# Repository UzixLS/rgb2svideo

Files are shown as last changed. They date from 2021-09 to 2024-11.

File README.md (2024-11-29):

## RGB2SVIDEO

This device converts 15KHz RGB + Sync analog video signal to S-Video or CVBS (composite) signal.
Both PAL and NTSC are supported (you should choose one at build).

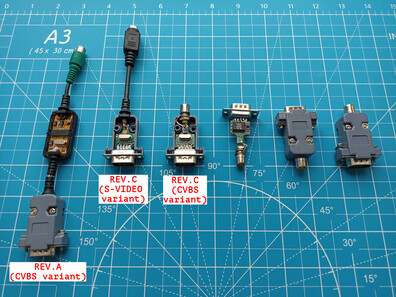
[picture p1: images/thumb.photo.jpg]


### Revision C PCB
This PCB is based on AD724 chip and designed to fit into DSUB shell.

[release/pcb.rev.C.pdf](release/pcb.rev.C.pdf?raw=true) - schematic and bill of materials  
[release/bom_interactive.rev.C.html](https://htmlpreview.github.io/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) - interactive BOM  
[release/gerber.rev.C.zip](release/gerber.rev.C.zip) - fabrication files  

### Revision A PCB
This PCB is based on BH7236AF/KA2198BD/CXA1645/CXA2075 chips and designed to fit into AK-S-71 shell.

[release/pcb.rev.A2.pdf](release/pcb.rev.A2.pdf?raw=true) - schematic and bill of materials  
[release/bom_interactive.rev.A2.html](https://htmlpreview.github.io/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) - interactive BOM  
[release/gerber.rev.A2.zip](release/gerber.rev.A2.zip) - fabrication files

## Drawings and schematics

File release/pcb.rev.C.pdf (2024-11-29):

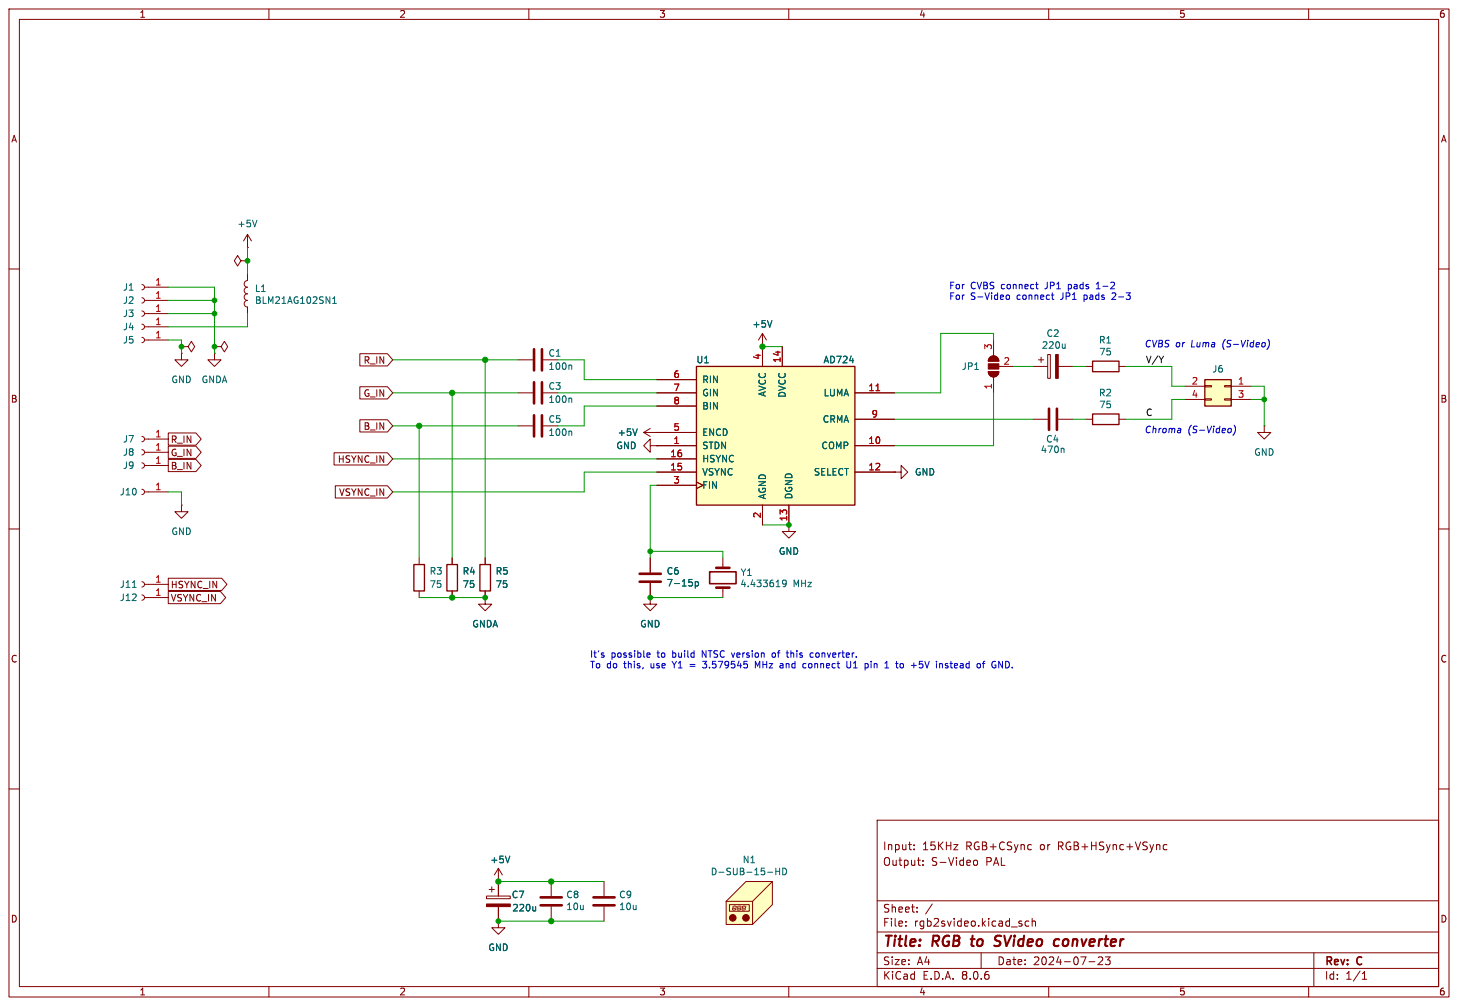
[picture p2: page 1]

4 ENCD 5 RIN 6 GIN 7 BIN 8 CRMA 9 U1 AD724 R3

4 ENCD 5 RIN 6 GIN 7 BIN 8 CRMA 9 GND

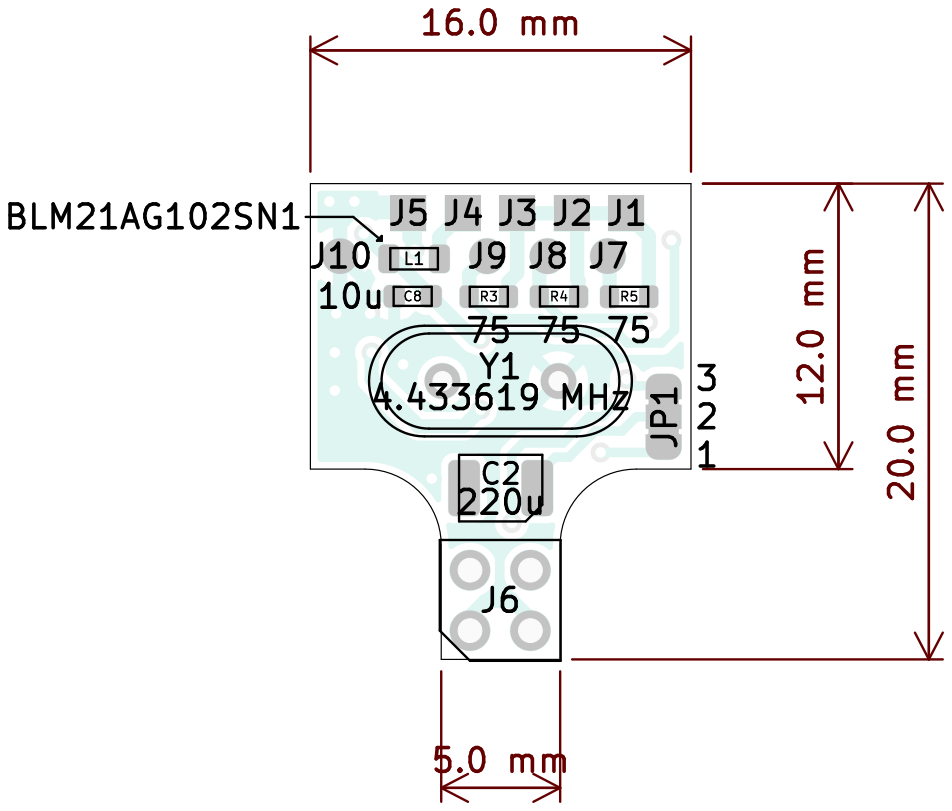
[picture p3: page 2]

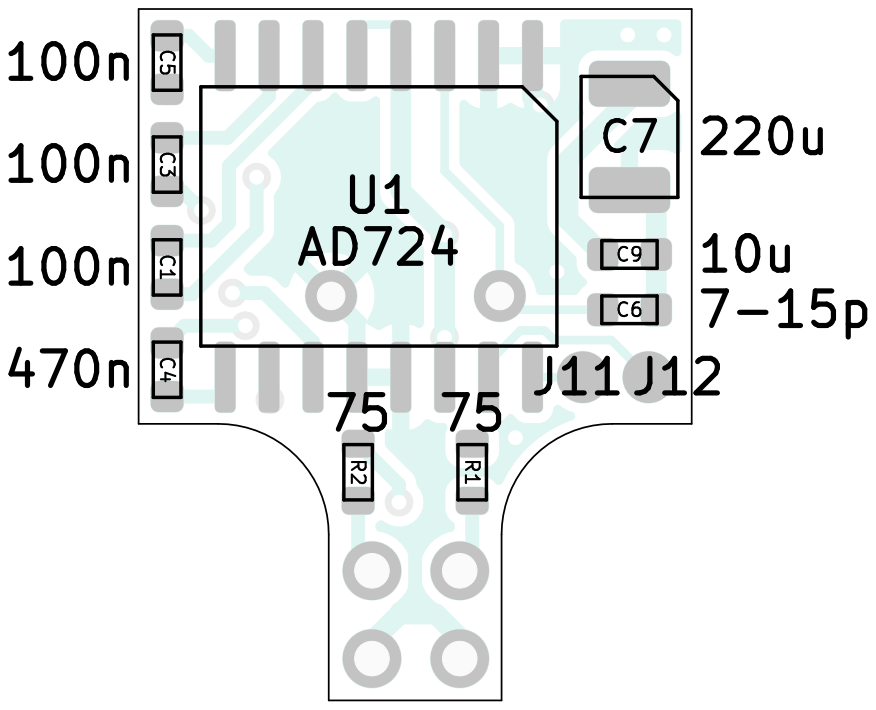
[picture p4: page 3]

# Bill Of Materials

References | | | Value | Footprint | Qty
C1 C3 C5 | 100n | Capacitor_SMD:C_0603_1608Metric | 3
C2 C7 | 220u | Capacitor_Tantalum_SMD:CP_EIA-3528-12_ Kemet-T | 2
C4 | 470n | Capacitor_SMD:C_0603_1608Metric | 1
C6 | 7-15p | Capacitor_SMD:C_0603_1608Metric | 1
C8 C9 | 10u | Capacitor_SMD:C_0603_1608Metric | 2
J6 | Conn_02x02_Odd_Even | Connector_PinHeader_2.54mm:PinHeader_2 x02_P2.54mm_Vertical | 1
L1 | BLM21AG102SN1 | Inductor_SMD:L_0805_2012Metric | 1
N1 | D-SUB-15-HD | | 1
R1 R2 R3 R4 R5 | 75 | Resistor_SMD:R_0603_1608Metric | 5
U1 | AD724 | Package_SO:SOIC-16W_7.5x10.3mm_P1.27 mm | 1
Y1 | 4.433619 MHz | Crystal:Crystal_HC49-4H_Vertical | 1

# rgb2svideo rev.C BOM page 1/1

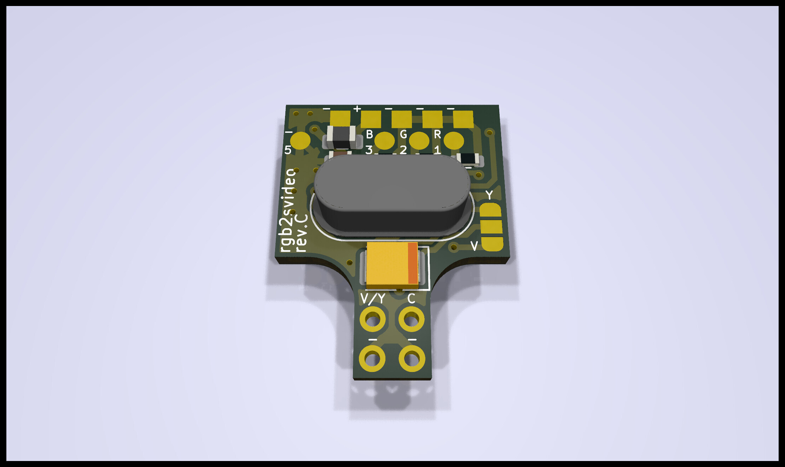
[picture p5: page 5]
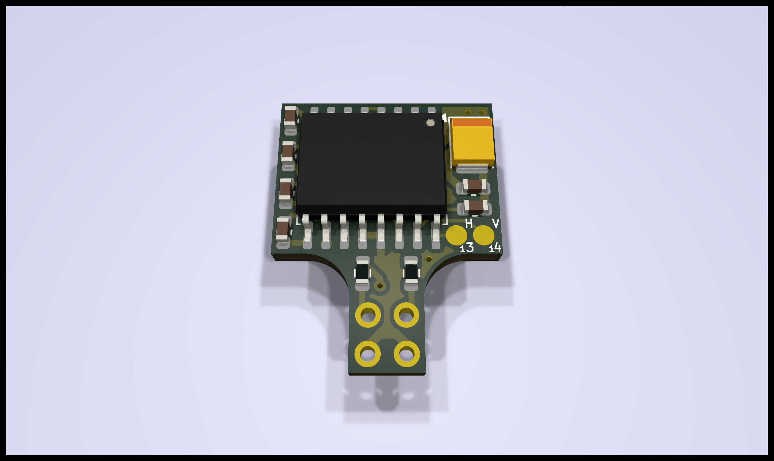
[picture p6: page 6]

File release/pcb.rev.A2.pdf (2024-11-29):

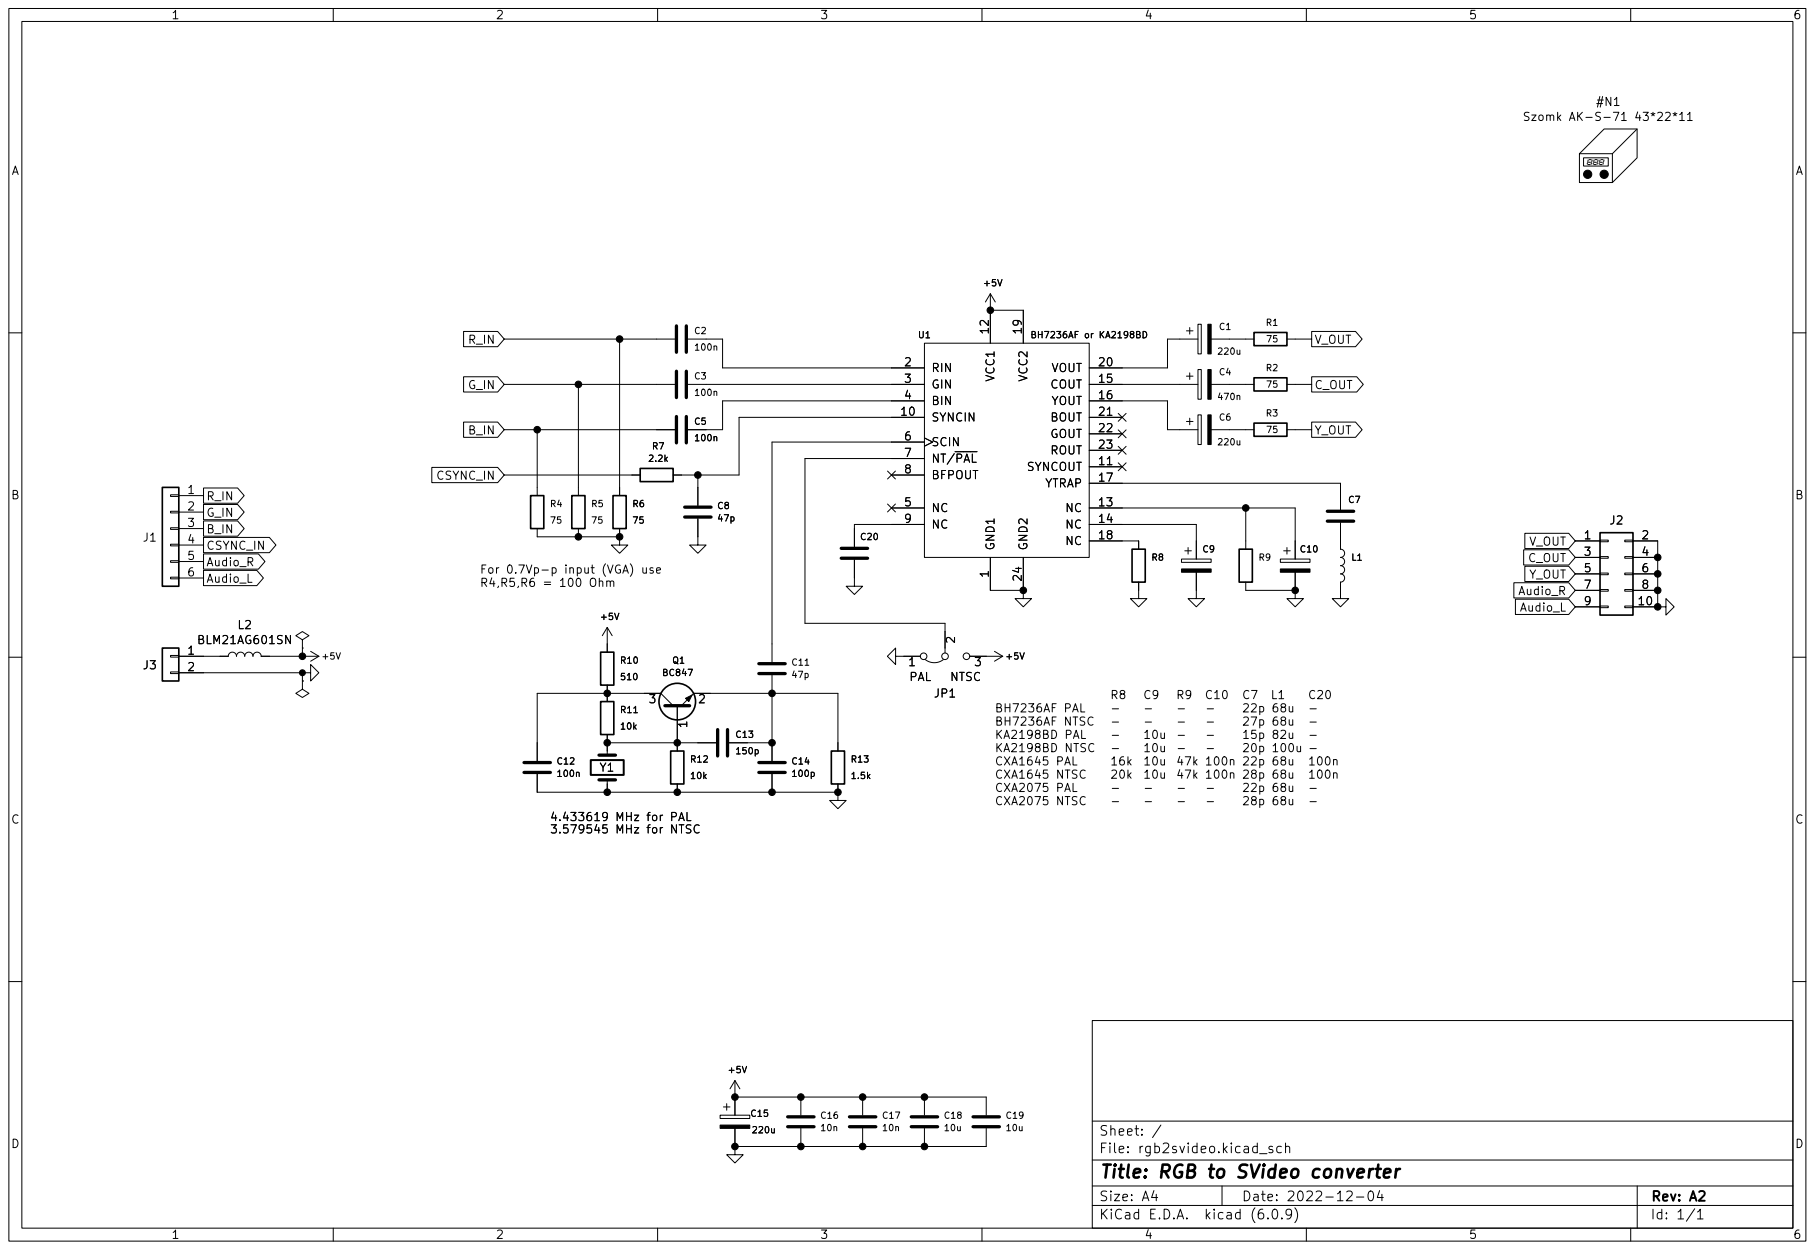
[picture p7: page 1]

For 0.7Vp-p input (VGA) use
R4,R5,R6 = 100 Ohm

Sheet: /
File: rgb2svideo.kicad_sch
Title: RGB to SVideo converter

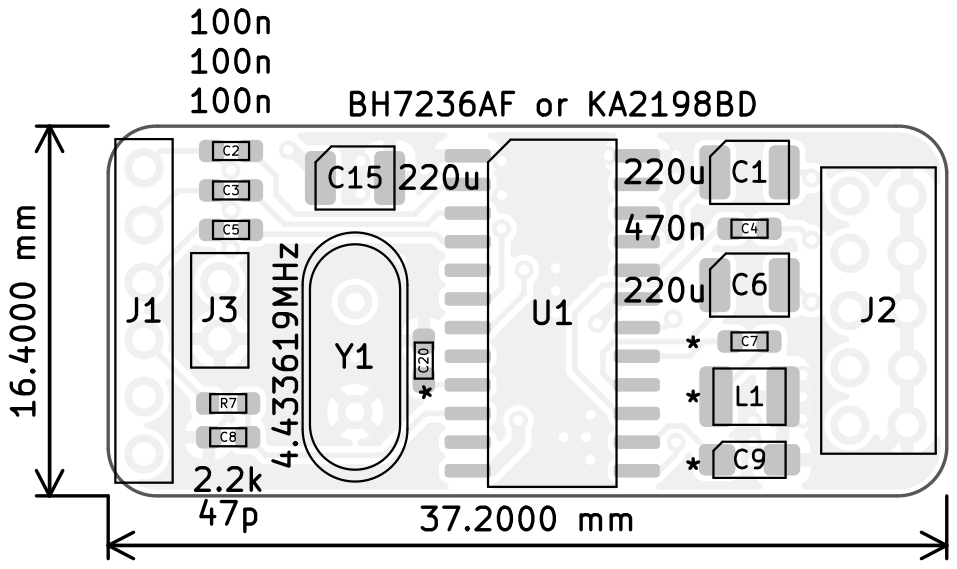
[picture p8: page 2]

Sheet: Assembly
File: rgb2svideo.kicad_pcb
Title: RGB to SVideo converter

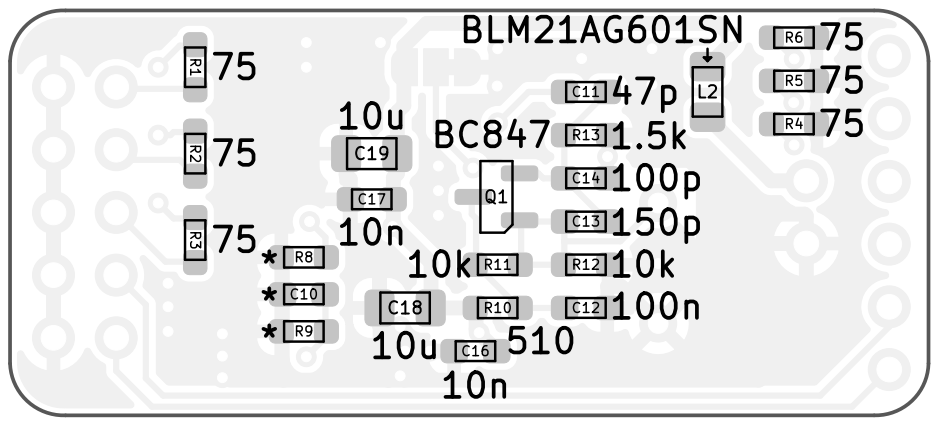
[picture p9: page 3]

Sheet: Assembly
File: rgb2svideo.kicad_pcb
Title: RGB to SVideo converter

Designator | Package | Value | Quantity
C1, C6, C15 | CP_EIA-3528-12_Kemet-T | 220u | 3
C2, C3, C5, C12 | C_0603_1608Metric_Pad1.08x0.95mm_HandSolder | 100n | 4
C4 | C_0603_1608Metric_Pad1.08x0.95mm_HandSolder | 470n | 1
C7, C10, C20 | C_0603_1608Metric_Pad1.08x0.95mm_HandSolder | * | 3
C8, C11 | C_0603_1608Metric_Pad1.08x0.95mm_HandSolder | 47p | 2
C9 | CP_EIA-3216-18_Kemet-A_Pad1.58x1.35mm_HandSolder | * | 1
C13 | C_0603_1608Metric_Pad1.08x0.95mm_HandSolder | 150p | 1
C14 | C_0603_1608Metric_Pad1.08x0.95mm_HandSolder | 100p | 1
C16, C17 | C_0603_1608Metric_Pad1.08x0.95mm_HandSolder | 10n | 2
C18, C19 | C_0805_2012Metric_Pad1.18x1.45mm_HandSolder | 10u | 2
L1 | L_1210_3225Metric_Pad1.42x2.65mm_HandSolder | * | 1
L2 | L_0805_2012Metric_Pad1.15x1.40mm_HandSolder | BLM21AG601SN | 1
Q1 | SOT-23 | BC847 | 1
R1, R2, R3, R4, R5, R6 | R_0603_1608Metric_Pad0.98x0.95mm_HandSolder | 75 | 6
R7 | R_0603_1608Metric_Pad0.98x0.95mm_HandSolder | 2.2k | 1
R8, R9 | R_0603_1608Metric_Pad0.98x0.95mm_HandSolder | * | 2
R10 | R_0603_1608Metric_Pad0.98x0.95mm_HandSolder | 510 | 1
R11, R12 | R_0603_1608Metric_Pad0.98x0.95mm_HandSolder | 10k | 2
R13 | R_0603_1608Metric_Pad0.98x0.95mm_HandSolder | 1.5k | 1
U1 | SOP-24_5.0x15.4mm_P1.27mm | BH7236AF or KA2198BD | 1
Y1 | Crystal_HC49-4H_Vertical | 4.433619MHz | 1

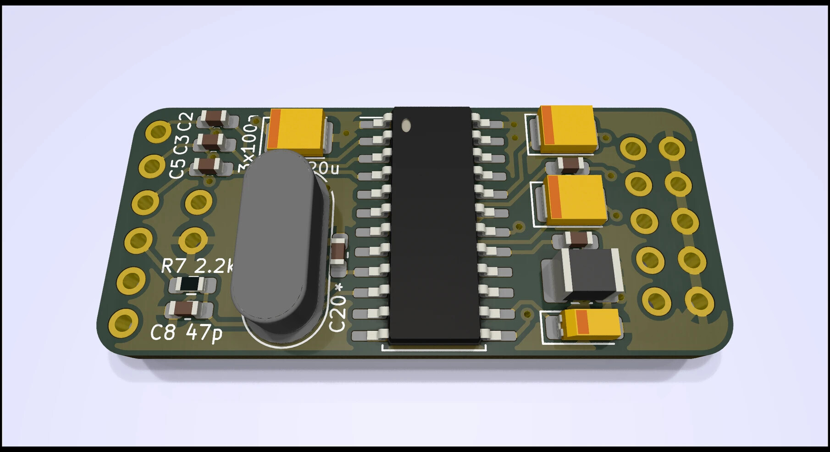
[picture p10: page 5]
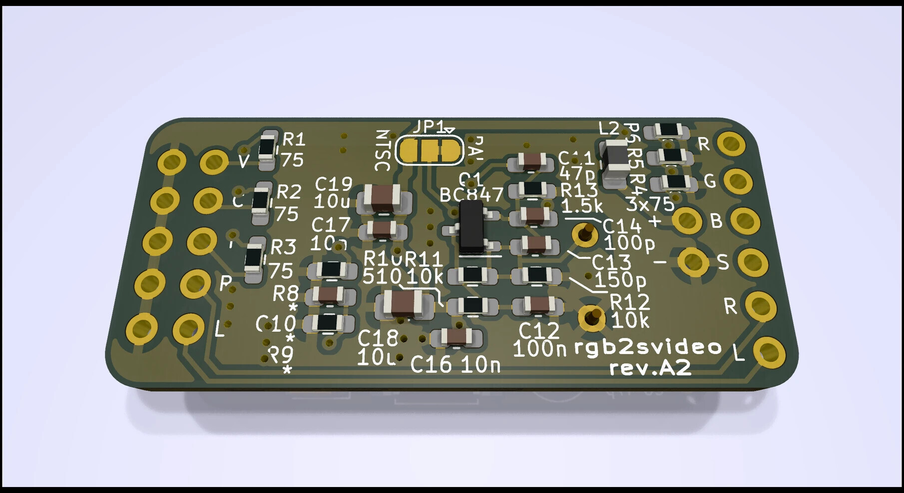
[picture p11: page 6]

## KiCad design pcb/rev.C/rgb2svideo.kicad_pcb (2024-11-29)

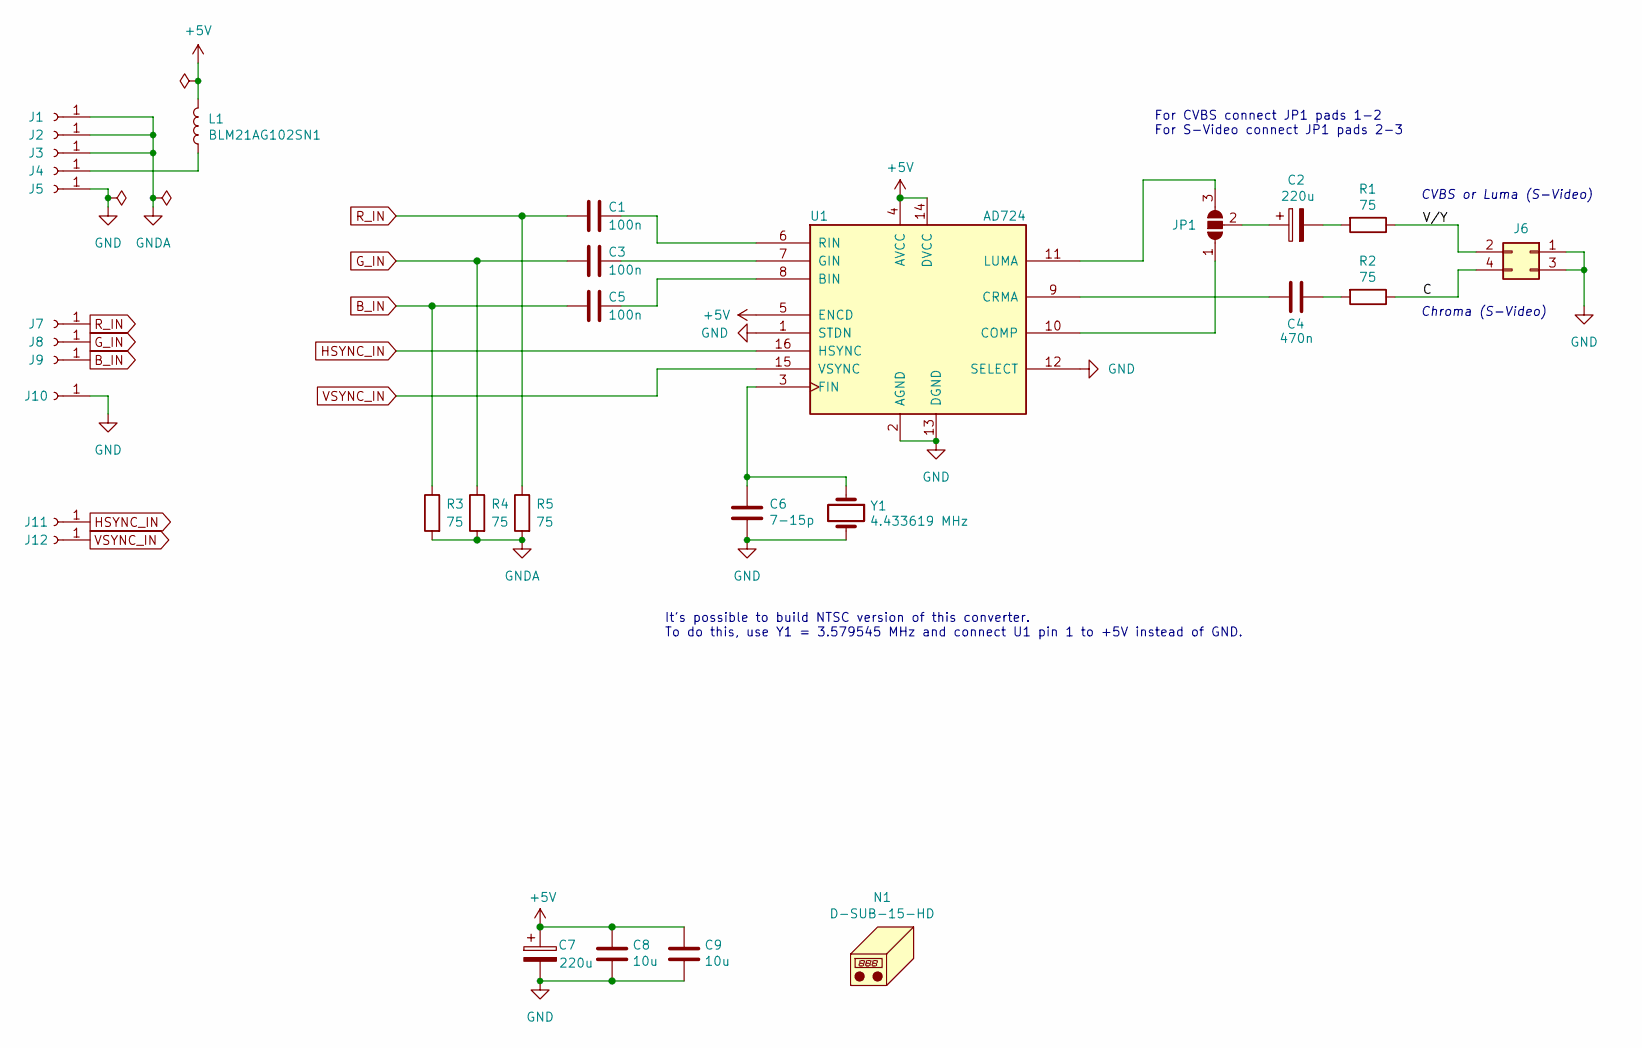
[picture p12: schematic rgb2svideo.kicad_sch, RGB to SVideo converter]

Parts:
C1, C3, C5: 100n; C_0603_1608Metric
C2, C7: 220u; CP_EIA-3528-12_Kemet-T
C4: 470n; C_0603_1608Metric
C6: 7-15p; C_0603_1608Metric
C8, C9: 10u; C_0603_1608Metric
J1, J2, J3, J4, J5: Conn_01x01_Socket; TestPoint_Pad_1.5x1.5mm
J6: Conn_02x02_Odd_Even; PinHeader_2x02_P2.54mm_Vertical
J7, J8, J9, J10, J11, J12: Conn_01x01_Socket; TestPoint_Pad_D1.5mm
JP1: SolderJumper_3_Bridged12; SolderJumper-3_P1.3mm_Open_RoundedPad1.0x1.5mm
L1: BLM21AG102SN1; L_0805_2012Metric
N1: D-SUB-15-HD
R1, R2, R3, R4, R5: 75; R_0603_1608Metric
U1: AD724; SOIC-16W_7.5x10.3mm_P1.27mm
Y1: 4.433619 MHz; Crystal_HC49-4H_Vertical

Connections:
+5V: C7.1, C8.1, C9.1, L1.2, U1.4 (AVCC), U1.5 (ENCD), U1.14 (DVCC)
/C: J6.4, R2.1
/V/Y: J6.2, R1.1
B_IN: C5.2, J9.1, R3.1
GND: C6.2, C7.2, C8.2, C9.2, J5.1, J6.1, J6.3, J10.1, U1.1 (STDN), U1.2 (AGND), U1.12 (SELECT), U1.13 (DGND), Y1.2
GNDA: J1.1, J2.1, J3.1, R3.2, R4.2, R5.2
G_IN: C3.2, J8.1, R4.1
HSYNC_IN: J11.1, U1.16 (HSYNC)
unnamed: C2.2, R1.2
unnamed: C4.2, R2.2
unnamed: J4.1, L1.1
unnamed: JP1.1 (A), U1.10 (COMP)
unnamed: JP1.3 (B), U1.11 (LUMA)
unnamed: C2.1, JP1.2 (C)
unnamed: C5.1, U1.8 (BIN)
unnamed: C4.1, U1.9 (CRMA)
unnamed: C6.1, U1.3 (FIN), Y1.1
unnamed: C3.1, U1.7 (GIN)
unnamed: C1.1, U1.6 (RIN)
R_IN: C1.2, J7.1, R5.1
VSYNC_IN: J12.1, U1.15 (VSYNC)

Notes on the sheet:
It's possible to build NTSC version of this converter. To do this, use Y1 = 3.579545 MHz and connect U1 pin 1 to +5V instead of GND.
For CVBS connect JP1 pads 1-2 For S-Video connect JP1 pads 2-3
CVBS or Luma (S-Video)
Chroma (S-Video)

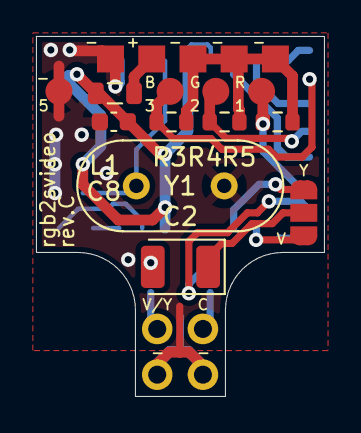
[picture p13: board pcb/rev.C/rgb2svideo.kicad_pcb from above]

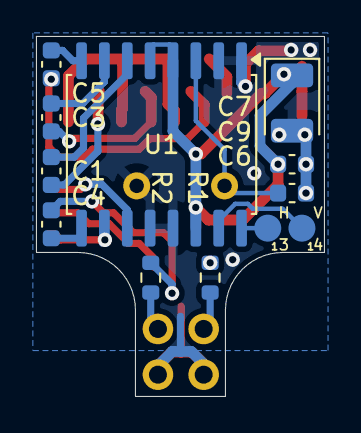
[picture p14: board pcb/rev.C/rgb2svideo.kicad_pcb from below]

Board: 2 copper layers, 16.0 x 20.0 mm, 30 parts (12 on the bottom side), 21 nets.

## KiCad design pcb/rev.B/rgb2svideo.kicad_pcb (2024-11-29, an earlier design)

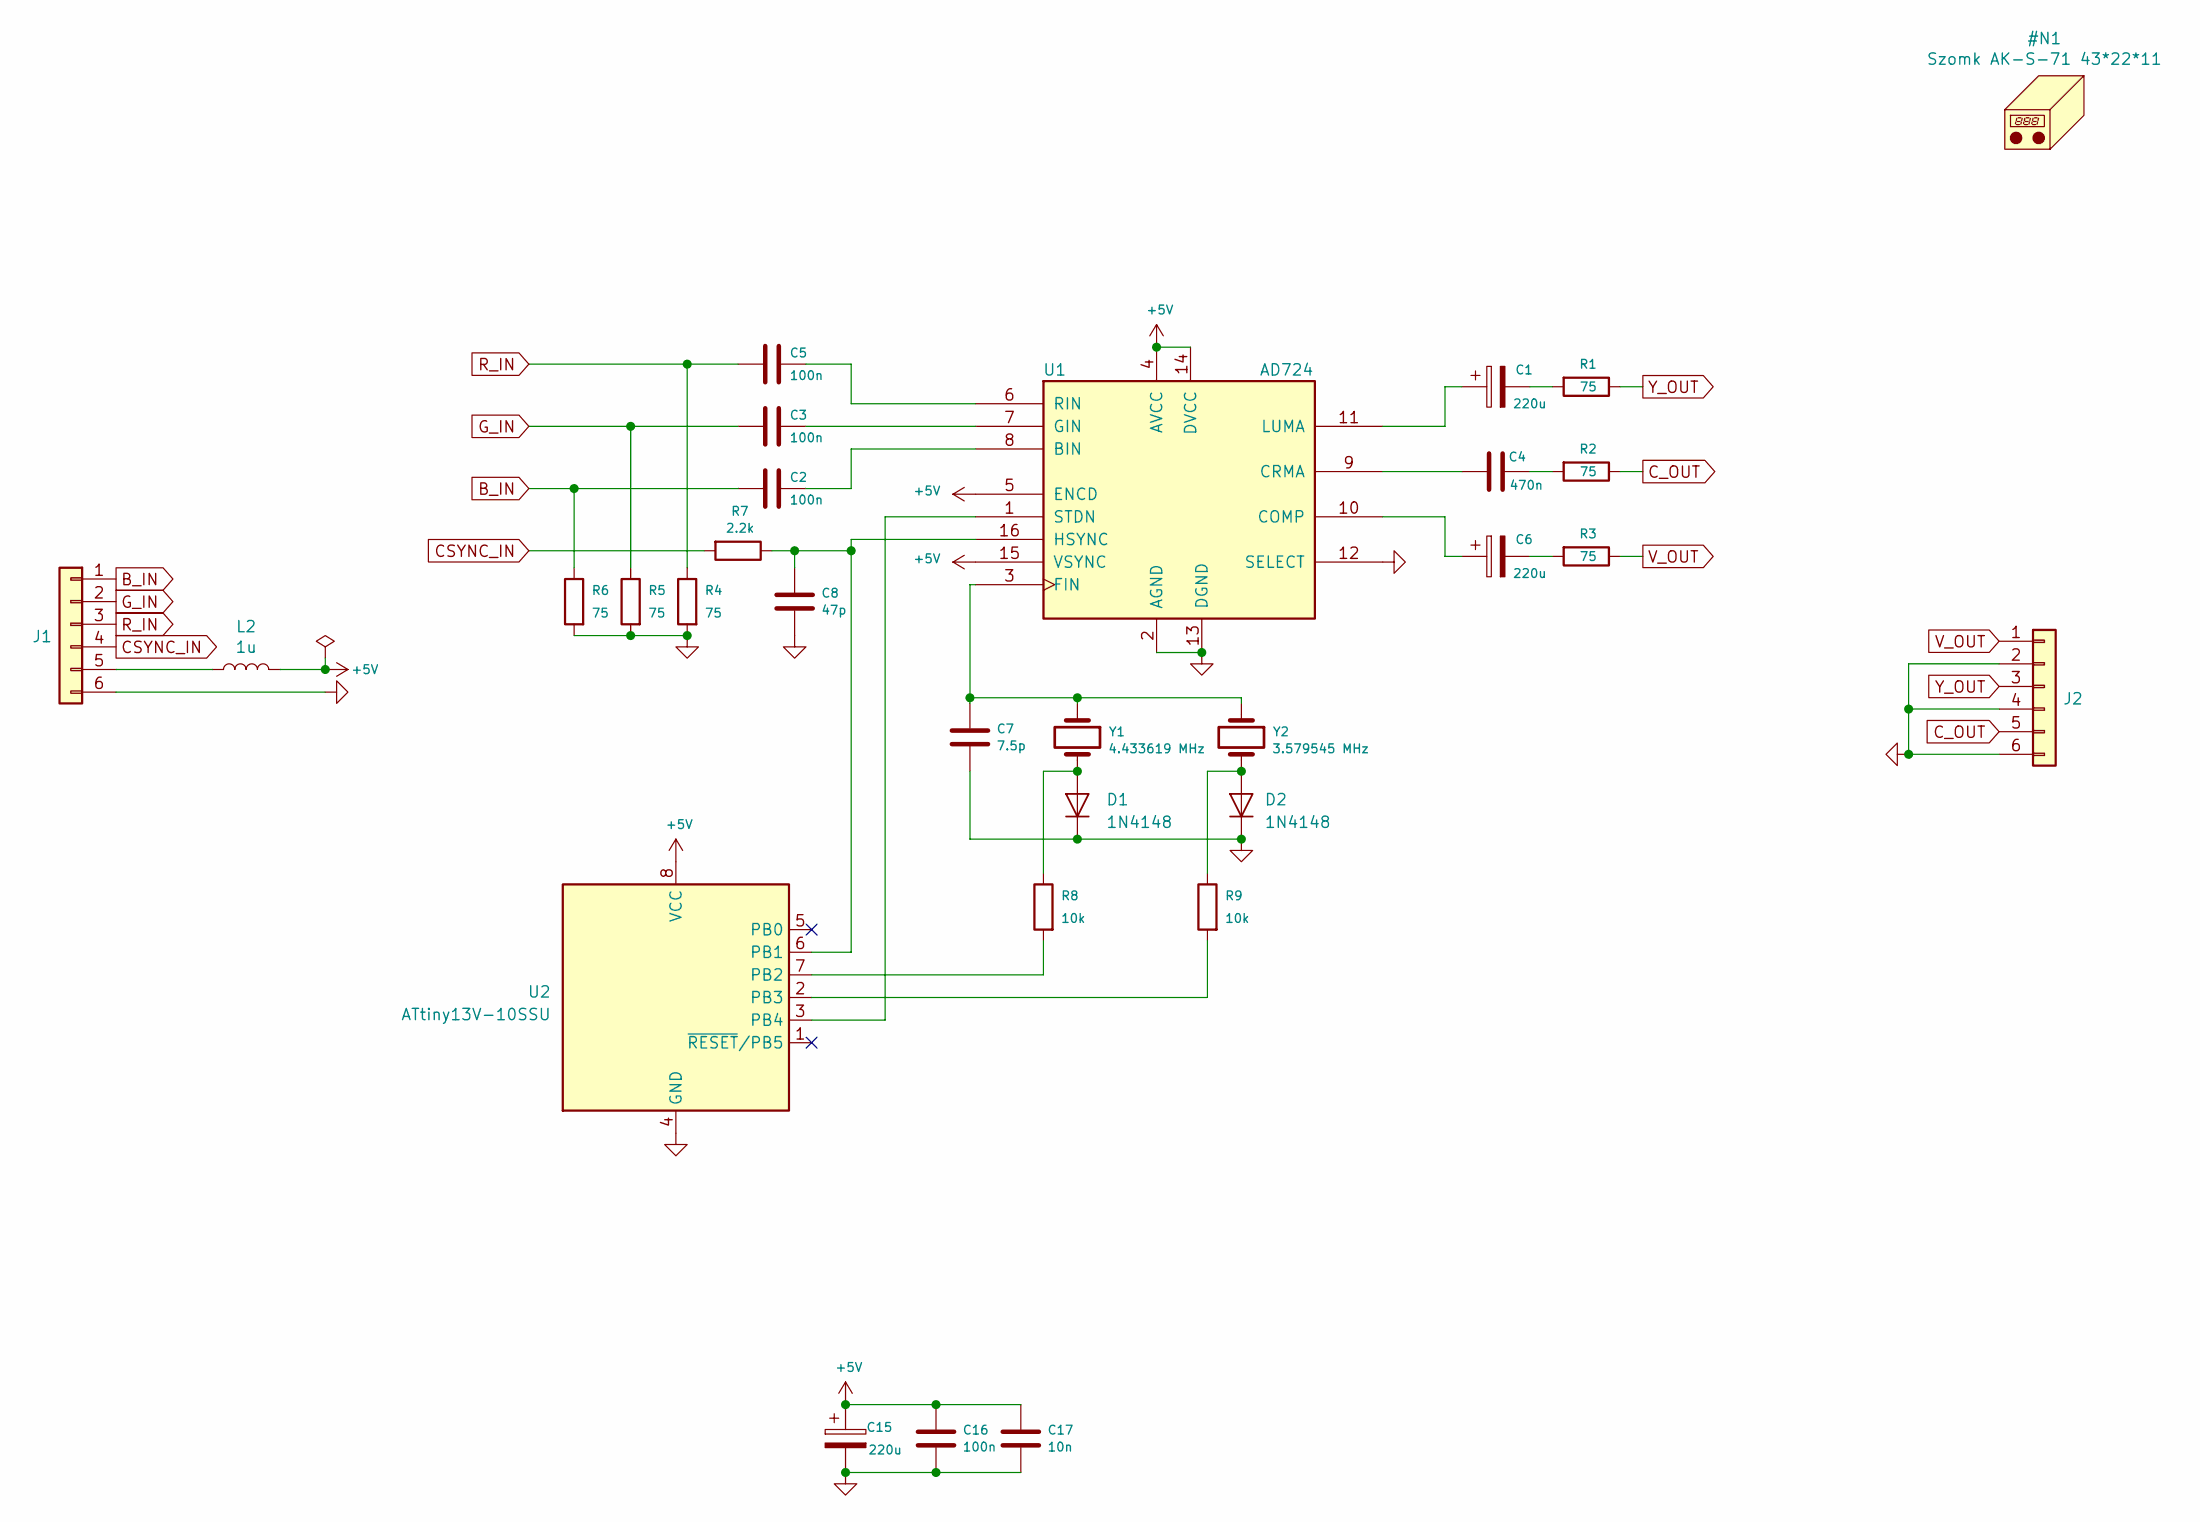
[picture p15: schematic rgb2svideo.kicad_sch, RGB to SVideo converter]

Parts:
C1, C6, C15: 220u; CP_EIA-3528-12_Kemet-T
C2, C3, C5: 100n; C_0603_1608Metric_Pad1.08x0.95mm_HandSolder
C4: 470n; C_0805_2012Metric_Pad1.18x1.45mm_HandSolder
C7: 7.5p; C_0603_1608Metric_Pad1.08x0.95mm_HandSolder
C8: 47p; C_0603_1608Metric_Pad1.08x0.95mm_HandSolder
C16: 100n; C_0603_1608Metric_Pad1.05x0.95mm_HandSolder
C17: 10n; C_0603_1608Metric_Pad1.05x0.95mm_HandSolder
D1, D2: 1N4148; D_0805_2012Metric_Pad1.15x1.40mm_HandSolder
J1, J2: Conn_01x06_Odd_Even; PinHeader_1x06_P2.54mm_Vertical
L2: 1u; L_0805_2012Metric_Pad1.15x1.40mm_HandSolder
R1, R2, R3, R4, R5, R6: 75; R_0603_1608Metric_Pad0.98x0.95mm_HandSolder
R7: 2.2k; R_0603_1608Metric_Pad0.98x0.95mm_HandSolder
R8, R9: 10k; R_0603_1608Metric_Pad0.98x0.95mm_HandSolder
U1: AD724; SOIC-16W_7.5x10.3mm_P1.27mm
U2: ATtiny13V-10SSU; SOIC-8_3.9x4.9mm_P1.27mm
Y1: 4.433619 MHz; Crystal_SMD_HC49-SD
Y2: 3.579545 MHz; Crystal_SMD_HC49-SD

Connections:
+5V: C15.1, C16.1, C17.1, L2.2, U1.4 (AVCC), U1.5 (ENCD), U1.14 (DVCC), U1.15 (VSYNC), U2.8 (VCC)
B_IN: C2.2, J1.1, R6.1
CSYNC_IN: J1.4, R7.2
C_OUT: J2.5, R2.1
GND: C7.2, C8.2, C15.2, C16.2, C17.2, D1.1 (K), D2.1 (K), J1.6, J2.2, J2.4, J2.6, R4.2, R5.2, R6.2, U1.2 (AGND), U1.12 (SELECT), U1.13 (DGND), U2.4 (GND)
G_IN: C3.2, J1.2, R5.1
unnamed: C1.1, U1.11 (LUMA)
unnamed: C1.2, R1.2
unnamed: C2.1, U1.8 (BIN)
unnamed: C3.1, U1.7 (GIN)
unnamed: C5.1, U1.6 (RIN)
unnamed: C6.1, U1.10 (COMP)
unnamed: C6.2, R3.2
unnamed: C8.1, R7.1, U1.16 (HSYNC), U2.6 (PB1)
unnamed: J1.5, L2.1
unnamed: C4.2, R2.2
unnamed: R8.2, U2.7 (PB2)
unnamed: R9.2, U2.2 (PB3)
unnamed: U1.1 (STDN), U2.3 (PB4)
unnamed: C7.1, U1.3 (FIN), Y1.1, Y2.1
unnamed: C4.1, U1.9 (CRMA)
unnamed: D1.2 (A), R8.1, Y1.2
unnamed: D2.2 (A), R9.1, Y2.2
R_IN: C5.2, J1.3, R4.1
V_OUT: J2.1, R3.1
Y_OUT: J2.3, R1.1

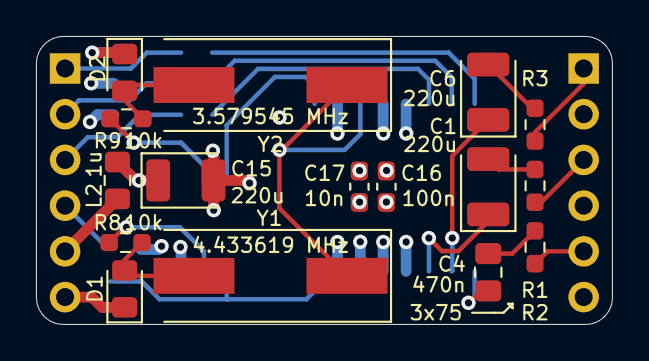
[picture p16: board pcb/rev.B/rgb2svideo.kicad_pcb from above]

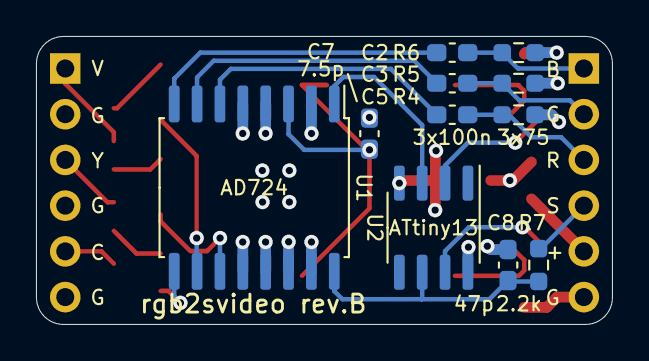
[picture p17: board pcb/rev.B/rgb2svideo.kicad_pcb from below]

Board: 4 copper layers, 32.0 x 16.0 mm, 29 parts (11 on the bottom side), 26 nets.

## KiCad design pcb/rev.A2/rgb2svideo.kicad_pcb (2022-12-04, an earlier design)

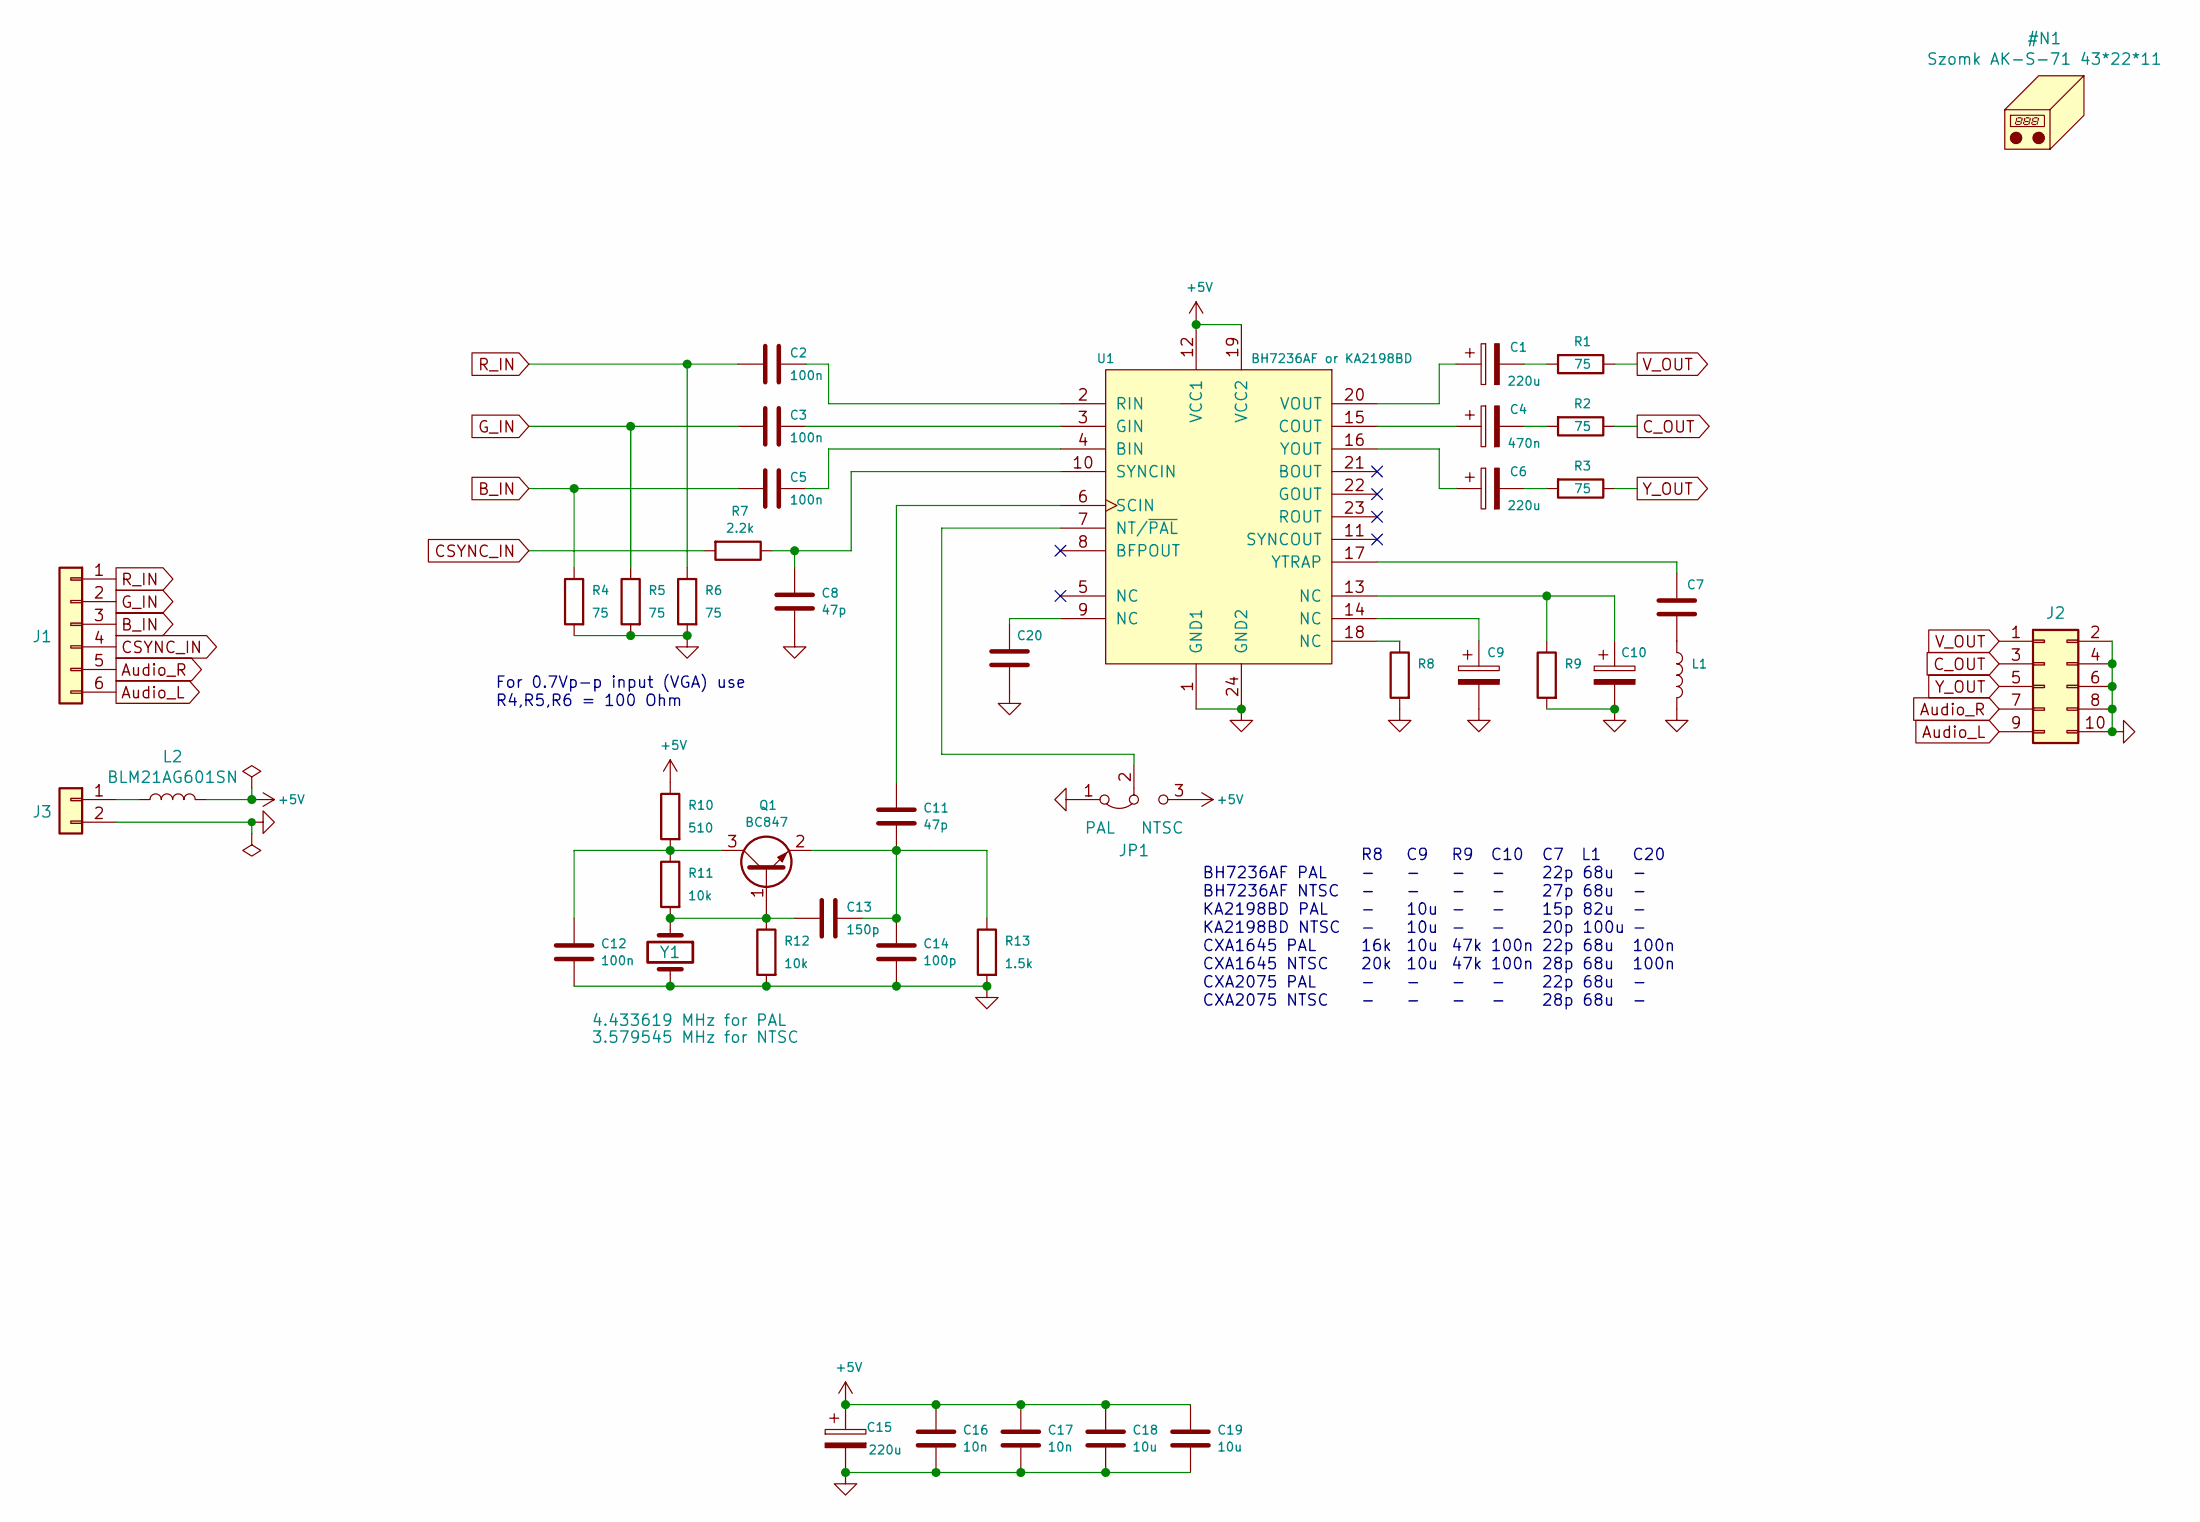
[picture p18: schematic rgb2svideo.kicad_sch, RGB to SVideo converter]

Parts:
C1, C6, C15: 220u; CP_EIA-3528-12_Kemet-T
C2, C3, C5, C12: 100n; C_0603_1608Metric_Pad1.08x0.95mm_HandSolder
C4: 470n; C_0603_1608Metric_Pad1.08x0.95mm_HandSolder
C7, C10, C20: *; C_0603_1608Metric_Pad1.08x0.95mm_HandSolder
C8, C11: 47p; C_0603_1608Metric_Pad1.08x0.95mm_HandSolder
C9: *; CP_EIA-3216-18_Kemet-A_Pad1.58x1.35mm_HandSolder
C13: 150p; C_0603_1608Metric_Pad1.08x0.95mm_HandSolder
C14: 100p; C_0603_1608Metric_Pad1.08x0.95mm_HandSolder
C16, C17: 10n; C_0603_1608Metric_Pad1.08x0.95mm_HandSolder
C18, C19: 10u; C_0805_2012Metric_Pad1.18x1.45mm_HandSolder
J1: Conn_01x06_Odd_Even; PinHeader_1x06_P2.54mm_Vertical
J2: Conn_02x05_Odd_Even; PinHeader_2x05_P2.54mm_Vertical
J3: Conn_01x02_Odd_Even; PinHeader_1x02_P2.54mm_Vertical
JP1: Jumper_3_Bridged12; SolderJumper-3_P1.3mm_Bridged12_RoundedPad1.0x1.5mm
L1: *; L_1210_3225Metric_Pad1.42x2.65mm_HandSolder
L2: BLM21AG601SN; L_0805_2012Metric_Pad1.15x1.40mm_HandSolder
Q1: BC847; SOT-23
R1, R2, R3, R4, R5, R6: 75; R_0603_1608Metric_Pad0.98x0.95mm_HandSolder
R7: 2.2k; R_0603_1608Metric_Pad0.98x0.95mm_HandSolder
R8, R9: *; R_0603_1608Metric_Pad0.98x0.95mm_HandSolder
R10: 510; R_0603_1608Metric_Pad0.98x0.95mm_HandSolder
R11, R12: 10k; R_0603_1608Metric_Pad0.98x0.95mm_HandSolder
R13: 1.5k; R_0603_1608Metric_Pad0.98x0.95mm_HandSolder
U1: BH7236AF or KA2198BD; SOP-24_5.0x15.4mm_P1.27mm
Y1: 4.433619MHz; Crystal_HC49-4H_Vertical

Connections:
+5V: C15.1, C16.1, C17.1, C18.1, C19.1, JP1.3 (B), L2.2, R10.1, U1.12 (VCC1), U1.19 (VCC2)
Audio_L: J1.6, J2.9
Audio_R: J1.5, J2.7
B_IN: C5.2, J1.3, R4.1
CSYNC_IN: J1.4, R7.2
C_OUT: J2.3, R2.1
GND: C8.2, C9.2, C10.2, C12.2, C14.2, C15.2, C16.2, C17.2, C18.2, C19.2, C20.1, J2.2, J2.4, J2.6, J2.8, J2.10, J3.2, JP1.1 (A), L1.2, R4.2, R5.2, R6.2, R8.2, R9.2, R12.2, R13.2, U1.1 (GND1), U1.24 (GND2), Y1.2
G_IN: C3.2, J1.2, R5.1
unnamed: C1.1, U1.20 (VOUT)
unnamed: C1.2, R1.2
unnamed: C2.1, U1.2 (RIN)
unnamed: C3.1, U1.3 (GIN)
unnamed: C4.1, U1.15 (COUT)
unnamed: C4.2, R2.2
unnamed: C5.1, U1.4 (BIN)
unnamed: C6.1, U1.16 (YOUT)
unnamed: C6.2, R3.2
unnamed: C7.1, L1.1
unnamed: C7.2, U1.17 (YTRAP)
unnamed: C8.1, R7.1, U1.10 (SYNCIN)
unnamed: C9.1, U1.14 (NC)
unnamed: C10.1, R9.1, U1.13 (NC)
unnamed: C11.1, U1.6 (SCIN)
unnamed: C11.2, C13.1, C14.1, Q1.2 (E), R13.1
unnamed: C12.1, Q1.3 (C), R10.2, R11.1
unnamed: C13.2, Q1.1 (B), R11.2, R12.1, Y1.1
unnamed: J3.1, L2.1
unnamed: JP1.2 (C), U1.7 (NT/~PAL)
unnamed: R8.1, U1.18 (NC)
unnamed: C20.2, U1.9 (NC)
R_IN: C2.2, J1.1, R6.1
V_OUT: J2.1, R1.1
Y_OUT: J2.5, R3.1

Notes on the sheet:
For 0.7Vp-p input (VGA) use R4,R5,R6 = 100 Ohm
C9 - - 10u 10u 10u 10u - -
R8 - - - - 16k 20k - -
R9 C10 - - - - - - - - 47k 100n 47k 100n - - - -
C7 L1 22p 68u 27p 68u 15p 82u 20p 100u 22p 68u 28p 68u 22p 68u 28p 68u
BH7236AF PAL BH7236AF NTSC KA2198BD PAL KA2198BD NTSC CXA1645 PAL CXA1645 NTSC CXA2075 PAL CXA2075 NTSC
C20 - - - - 100n 100n - -

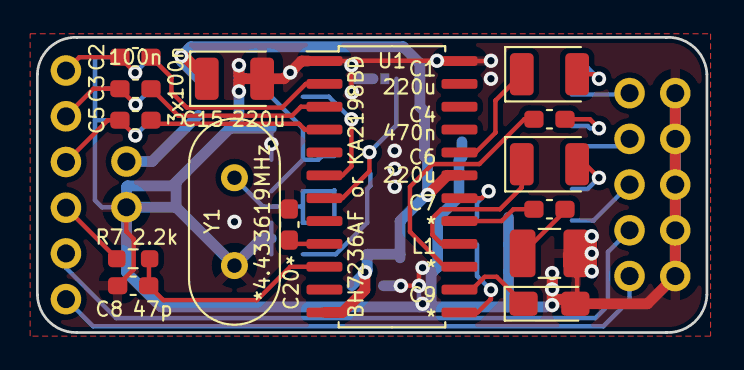
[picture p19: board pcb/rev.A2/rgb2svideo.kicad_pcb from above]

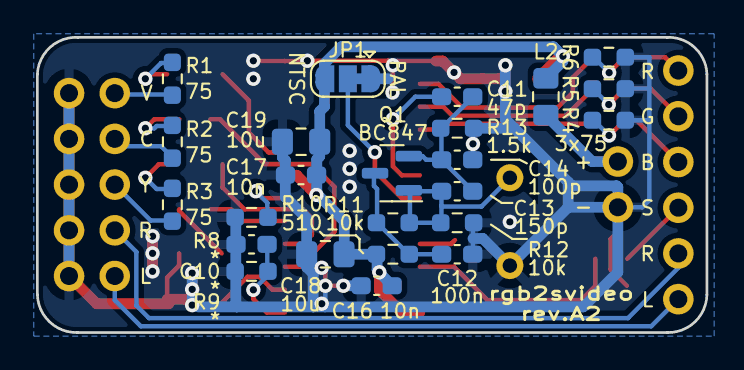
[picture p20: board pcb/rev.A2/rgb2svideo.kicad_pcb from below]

Board: 2 copper layers, 37.2 x 16.4 mm, 42 parts (24 on the bottom side), 33 nets.

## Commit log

2021-09-04 add pcb rev.A
    [rgb2svideo.kicad_pcb, rgb2svideo.kicad_sch]
2021-09-04 add pcb rev.A1
    [rgb2svideo.kicad_pcb, rgb2svideo.kicad_sch]
2021-09-04 add gerbers, renders and pdf for rev.A1
2022-12-04 add pcb rev.A2
    [rgb2svideo.kicad_pcb, rgb2svideo.kicad_sch]
2022-12-04 add gerbers, renders and pdf for rev.A2
2022-12-04 remove gerbers, renders and pdf for rev.A1
2024-11-29 add pcb rev.B source files
    [rgb2svideo.kicad_pcb, rgb2svideo.kicad_sch]
2024-11-29 add pcb rev.C source files
    [rgb2svideo.kicad_pcb, rgb2svideo.kicad_sch]
2024-11-29 add pcb rev.C release files
